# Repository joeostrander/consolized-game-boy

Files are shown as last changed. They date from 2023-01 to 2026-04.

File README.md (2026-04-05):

# consolized-game-boy

This repository contains the current state of the consolized Game Boy project, based on Andy West's original Game Guy project. It's evolved a bit since then, now supporting multiple controller options, custom PCBs, RP2040 and RP2350 support and a newer HDMI-compatible DVI output path with audio (no VGA2HDMI adapter required).

The core idea is still the same: build a self-contained Game Boy console around harvested Game Boy hardware, with video, controls, power, and enclosure work integrated into a compact custom build.

Recent major addition:
- 2026-04-04: HDMI-compatible DVI firmware and hardware path, including digital video plus audio output.

gameplay

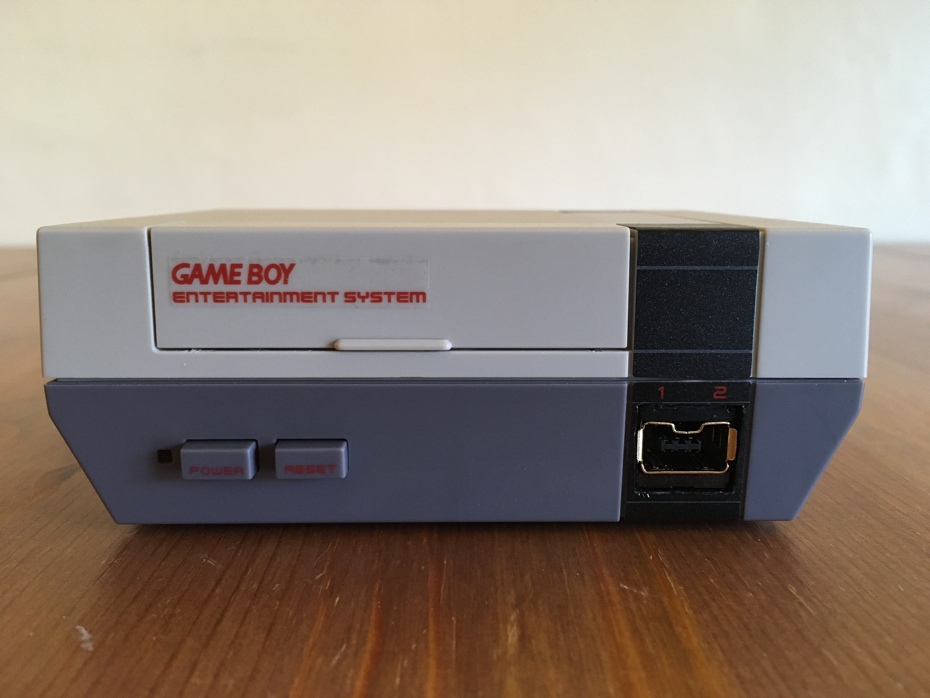
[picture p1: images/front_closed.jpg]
front closed


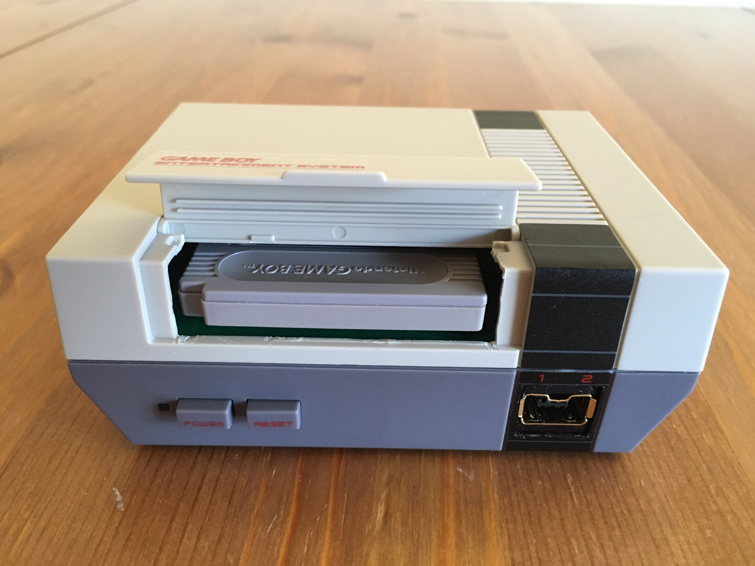
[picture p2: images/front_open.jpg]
front open


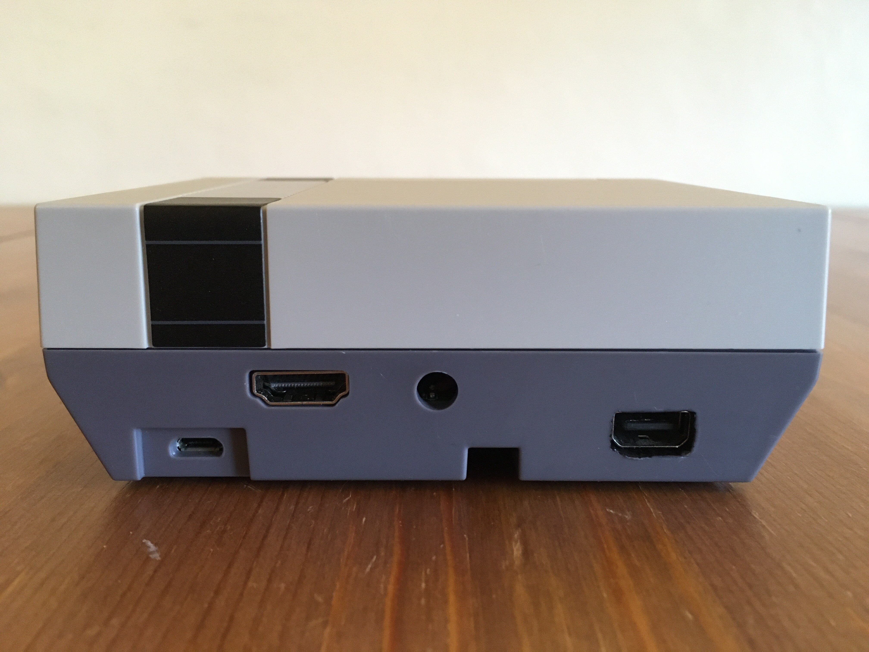
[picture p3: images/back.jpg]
back


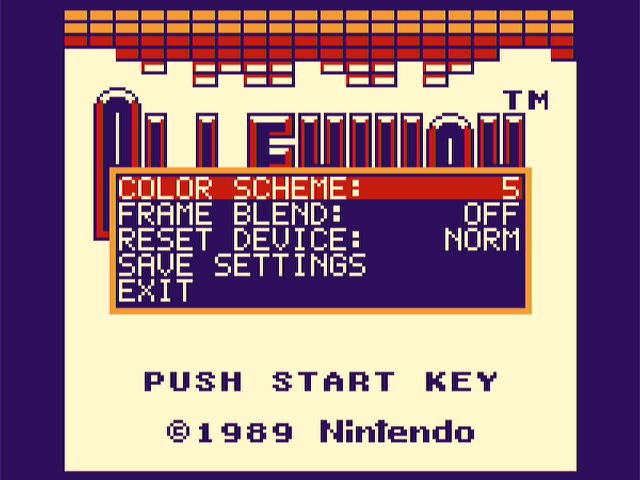
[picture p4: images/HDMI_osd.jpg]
hdmi osd


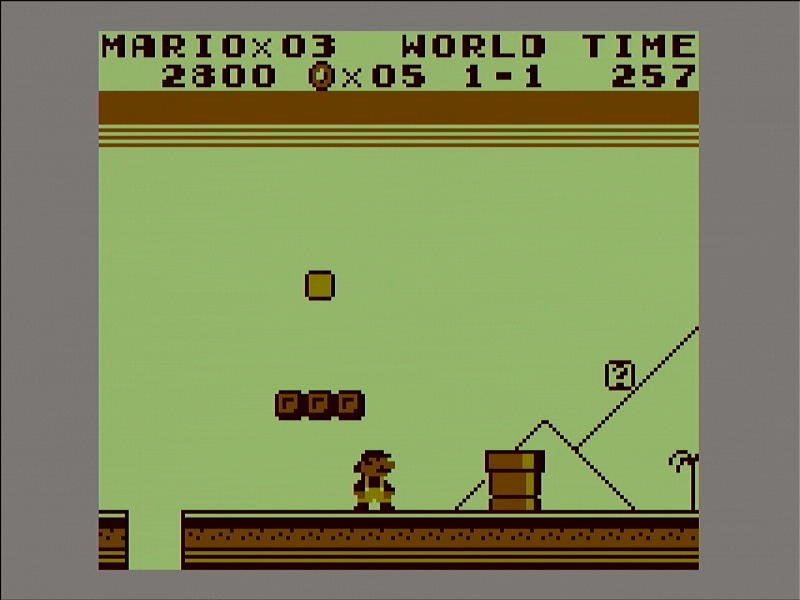
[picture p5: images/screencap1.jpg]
screencap 1


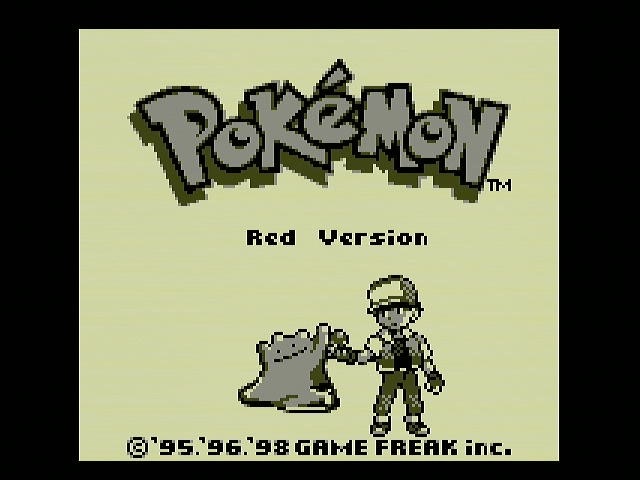
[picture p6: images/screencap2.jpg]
screencap 2


HDMI (DVI)

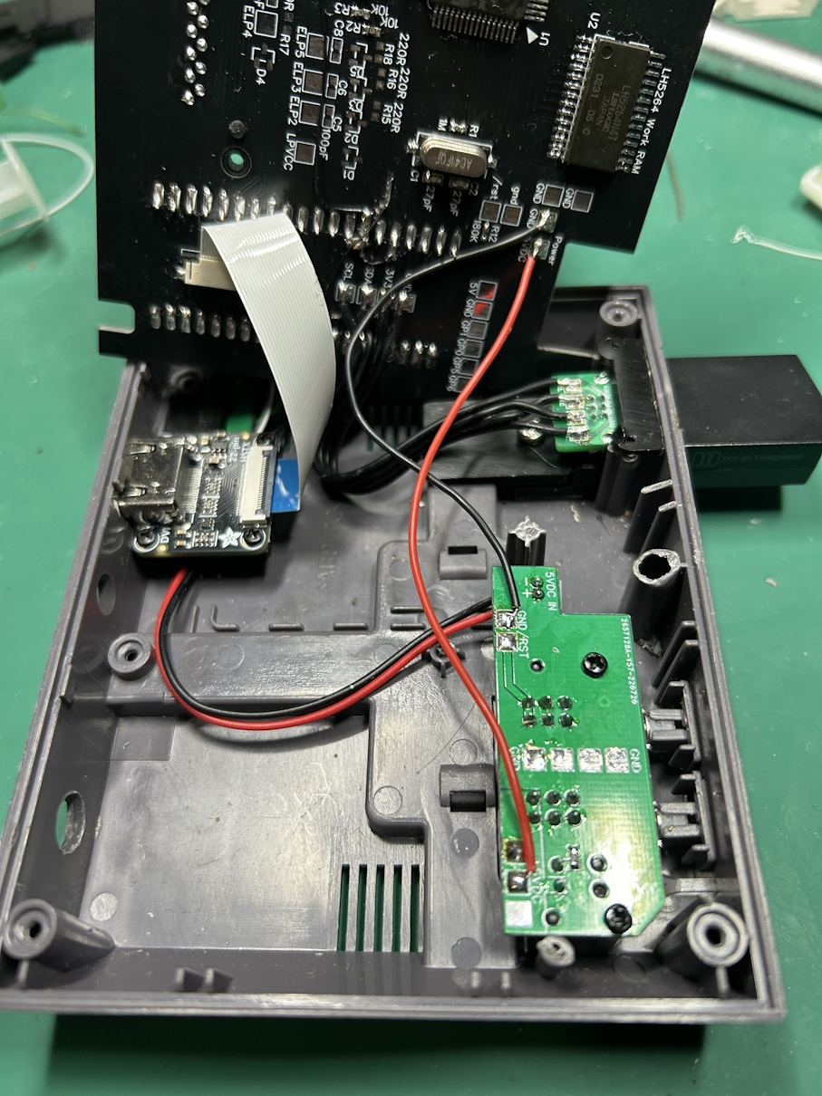
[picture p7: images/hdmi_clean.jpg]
hdmi clean


## What This Project Includes

- Single-Pico firmware designs
- VGA output firmware with RGB222 and RGB332 variants
- HDMI-compatible DVI output firmware with audio
- RP2040 and RP2350 build targets
- NES shift-register controller support
- NES Classic / Wii I2C controller support
- On-screen display for settings and runtime controls
- Saved settings in flash
- Custom motherboard and breakout PCBs
- 3D-printable case and mount parts
- Support for harvesting CPU and RAM from a Super Game Boy SNES/Famicom cartridge
- Link port support, with credit to Markeno for the PCB mod

## Repository Layout

| Path | Purpose |
| --- | --- |
| `src/gb_vga` | VGA firmware project |
| `src/gb_dvi` | HDMI-compatible DVI firmware project |
| `src/buildall.cmd` | Batch wrapper that builds every currently scripted firmware variant |
| `src/find_picotool.cmd` | Shared helper that tries to reuse an existing `picotool` build |
| `src/find_rpi_rp2_drive.cmd` | Shared helper that detects a mounted `RPI-RP2` device |
| `docs` | BOMs and PDF schematics |
| `easyeda` | EasyEDA project archives |
| `gerber` | Gerber archives for motherboard and breakout boards |
| `3D` | STL files for mounts, controller jack holders, and case-specific pieces |
| `images` | Photos, screenshots, and wiring / PCB reference images |

## Hardware Assets

The repository now contains the hardware files needed to reproduce both the VGA and DVI versions.

### Documentation

- `docs/VGA_BOM_V3_2_2_SGB_CART_2023-01-14.csv`
- `docs/VGA_schematic_sgb_cart_V3.2.2_2023-01-18.pdf`
- `docs/HDMI_BOM_SGB_CART.csv`
- `docs/HDMI_schematic_dvi_V2.pdf`

### PCB Archives

EasyEDA source archives are in `easyeda/`.

Gerbers are in `gerber/`, including:

- VGA SGB-cart motherboard variants
- VGA SMD-cart motherboard variant
- HDMI / DVI SGB-cart motherboard variant
- Link port breakout
- NES breakout
- Power / reset board
- USB with data board
- Wii jack breakout

### 3D Printed Parts

STLs are in `3D/`, including VGA and HDMI-specific mounts and Wii jack holder parts.

## Firmware Variants

There are now two firmware families in the repo.

### 1. VGA firmware

Project path:

- `src/gb_vga`

Prebuilt release naming:

- `gb_vga_<platform>_<video>_<controller>.uf2`

Examples:

- `gb_vga_rp2040_rgb222_nes.uf2`
- `gb_vga_rp2040_rgb332_wii.uf2`
- `gb_vga_rp2350_rgb222_nes.uf2`

Options:

- `platform`: `rp2040` or `rp2350`
- `video`: `rgb222` or `rgb332`
- `controller`: `nes` or `wii`

Notes:

- `rgb222` uses fewer GPIOs and is the default VGA output mode in the build script.
- `wii` means the NES Classic / Wii I2C controller path.
- `nes` means the original shift-register controller path.

### 2. HDMI-compatible DVI firmware

Project path:

- `src/gb_dvi`

Prebuilt release naming:

- `dmg_dvi_<platform>_res<mode>_<controller>.uf2`

Examples:

- `dmg_dvi_rp2040_res0_nes.uf2`
- `dmg_dvi_rp2040_res2_wii.uf2`
- `dmg_dvi_rp2350_res1_wii.uf2`

Options:

- `platform`: `rp2040` or `rp2350`
- `mode`: `0`, `1`, or `2`
- `controller`: `nes` or `wii`

Display modes:

- `0`: 640x480 output, horizontally scaled x4 and vertically x3 for full-screen 640x480 presentation
- `1`: 800x600 output, horizontally scaled x4 and vertically x4 for a 640x576 window
- `2`: 640x480 output, horizontally scaled x2 and vertically x2 for a 320x288 window

## Prebuilt Firmware

If you do not want to build from source, use the `.uf2` files from the [Releases](https://github.com/joeostrander/consolized-game-boy/releases) page.

Current release coverage in this repository includes:

- 12 DVI variants: 2 platforms x 3 display modes x 2 controller types
- 8 VGA variants: 2 platforms x 2 video formats x 2 controller types

Choose the file that matches:

1. Your board: `rp2040` for Pico, `rp2350` for Pico 2
2. Your output path: `gb_vga_*` for VGA, `dmg_dvi_*` for HDMI-compatible DVI
3. Your controller wiring: `nes` or `wii`
4. Your display mode: `rgb222` / `rgb332` for VGA, or `res0` / `res1` / `res2` for DVI

To flash, hold BOOTSEL on the Pico / Pico 2, connect USB, then copy the matching `.uf2` to the `RPI-RP2` drive.

## Building From Source

The firmware projects can now be built from this repository directly; they do not need to live under `C:\VSARM\sdk\pico`.

### Common Requirements

- Windows build environment with `cmake` and MinGW available on `PATH`
- A valid Pico SDK checkout exposed via `PICO_SDK_PATH`
- `picotool` available if you want `.uf2` output

The wrapper scripts try to reuse an existing `picotool` package from a sibling VSARM `gb_vga` or `gb_dvi` build when one is available.

If a target device is mounted as `RPI-RP2`, the build scripts will also try to copy the generated `.uf2` automatically.

### Building VGA

Extra requirement for VGA:

- Pico Extras must be available through `PICO_EXTRAS_PATH`, or placed as a sibling of the SDK checkout so `pico_scanvideo_dpi` can be found.

Build from `src/gb_vga`:

```bat
build_clean.cmd
build_clean.cmd rp2040 rgb222 nes
build_clean.cmd rp2040 rgb332 wii
build_clean.cmd rp2350 rgb222 nes
build_clean.cmd rp2350 rgb332 wii
```

Argument format:

```text
build_clean.cmd [rp2040|rp2350] [rgb222|rgb332] [nes|wii]
```

### Building DVI

Build from `src/gb_dvi`:

```bat
build_clean.cmd
build_clean.cmd rp2040 0 nes
build_clean.cmd rp2350 2 wii

build.cmd
build.cmd rp2040 0 nes
build.cmd rp2350 2 wii
```

Argument format:

```text
build_clean.cmd [rp2040|rp2350] [0|1|2] [nes|wii]
build.cmd       [rp2040|rp2350] [0|1|2] [nes|wii]
```

Notes:

- `build_clean.cmd` always recreates the build directory.
- `build.cmd` tries to reuse the existing build and will recreate it if cached settings no longer match the requested platform, resolution mode, or controller type.

### Building Every Scripted Variant

From `src/`:

```bat
buildall.cmd
```

This runs the full scripted matrix for both projects:

- 12 DVI builds
- 8 VGA builds

It stops on the first failure so the failing variant is easy to identify.

## Project Notes

- VGA uses Pico Extras because `pico_scanvideo_dpi` is provided there.
- DVI does not need Pico Extras.
- The DVI firmware supports audio output in addition to digital video.
- Both firmware families expose controller selection at build time.
- Both firmware families now support RP2040 and RP2350 targets.

## Videos

Demo:

RGB332 Video Demo (https://youtu.be/dT88XEHc5w8)

Andy liked my modifications and made an updated video where he built one with my changes:

The Game Guy Mini, Upgrading the Unportable Game Boy! (https://youtu.be/gPNHySf-hk0)

Original video:

Game Guy - The Unportable Game Boy (https://www.youtube.com/watch?v=ypGMU5lLjeU)

element14 Community pages:

- https://community.element14.com/challenges-projects/element14-presents/project-videos/w/documents/27407
- https://community.element14.com/w/documents/27862/episode-577-the-game-guy-mini-upgrading-the-unportable-game-boy

## Credits

- Andy West for the original concept and code
- Joe Ostrander for the later firmware, hardware, controller, OSD, flash-save, scaling, and newer DVI work in this repo
- Markeno for the link port PCB motherboard design addition
- Supertazon for waterslide logo and help on frameblending
- other members of element14 community that I've forgot

## See also

- [PicoDVI-DMG](https://github.com/joeostrander/PicoDVI-DMG)
- [PicoDVI-DMG_EMU](https://github.com/joeostrander/PicoDVI-DMG_EMU) - Emulator version

## Contact
For questions or collaboration, reach me at:  
joeostrander [at] protonmail [dot] com

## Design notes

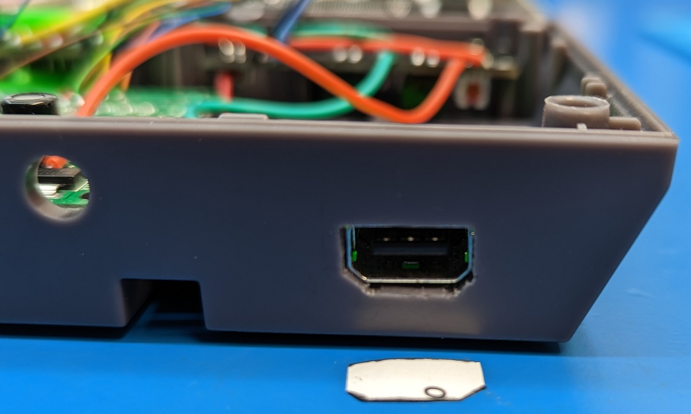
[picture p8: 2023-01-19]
images/v3_2_lp5.jpg

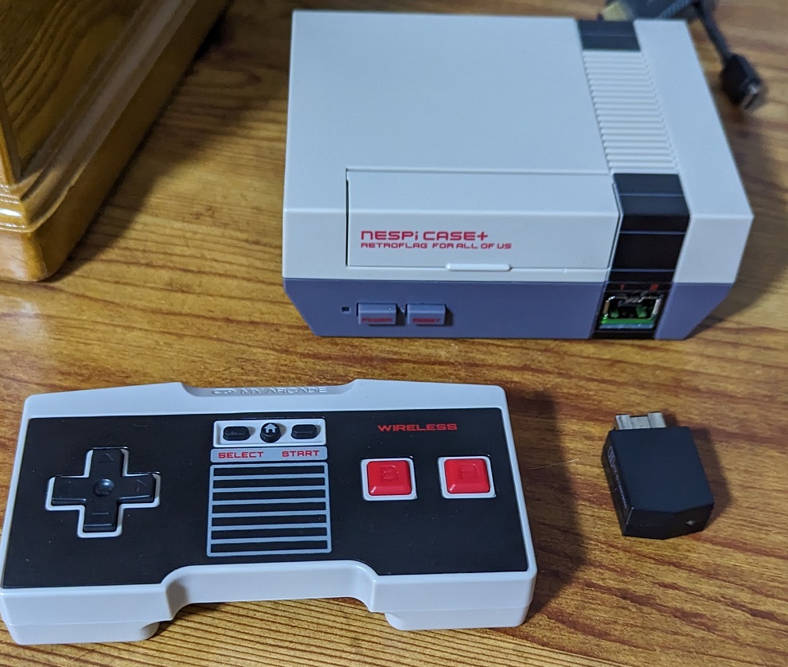
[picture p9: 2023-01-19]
images/v3_2_front.jpg

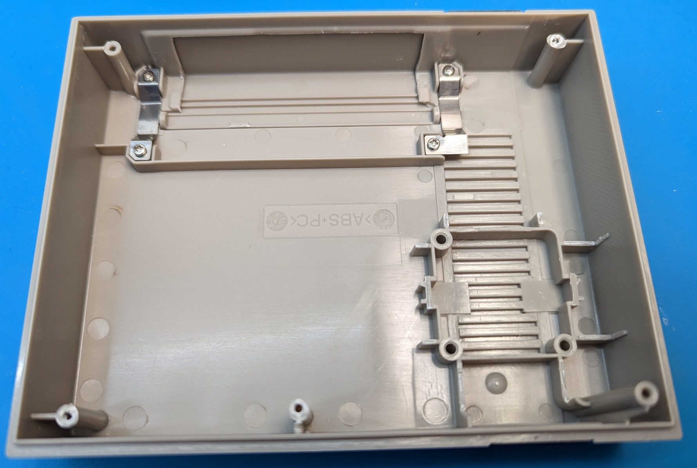
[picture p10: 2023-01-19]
images/v3_2_top_inside.jpg

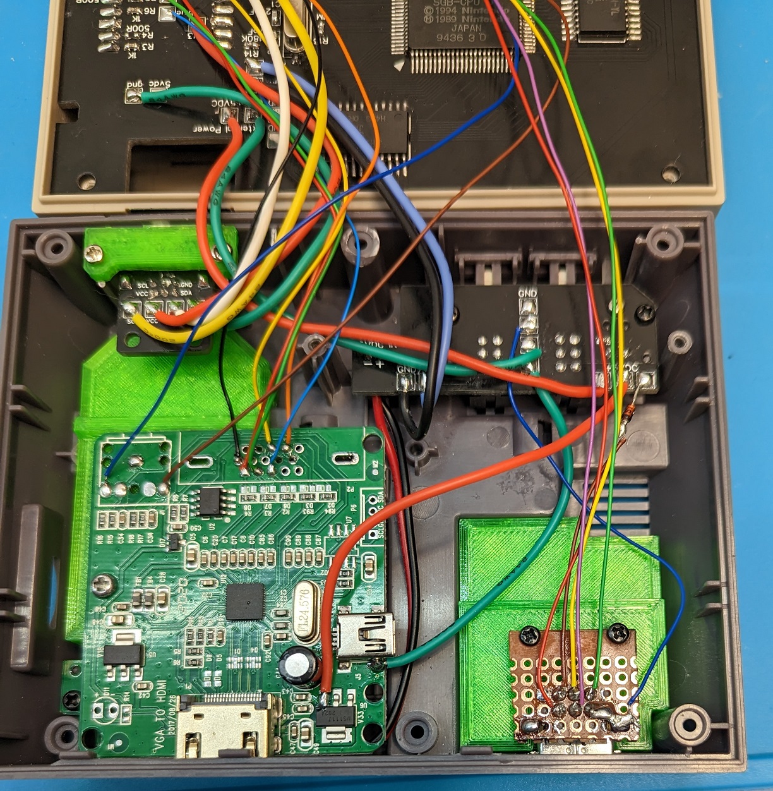
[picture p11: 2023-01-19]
images/v3_2_lp7.jpg

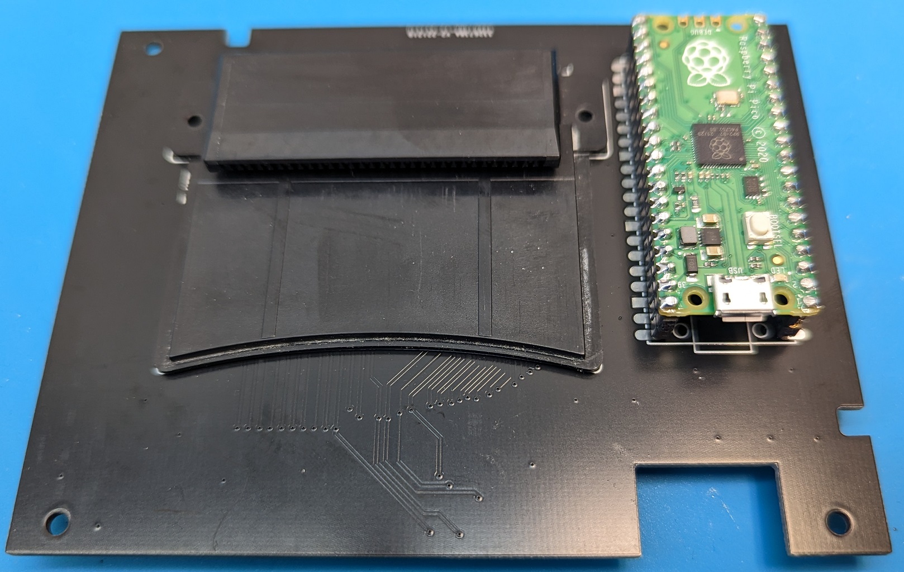
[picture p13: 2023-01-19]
images/v3_2_topside.jpg

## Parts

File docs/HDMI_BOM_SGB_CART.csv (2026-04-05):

Game Boy Console BOM
Name | Designator | Footprint | Quantity | Manufacturer Part | Manufacturer | Link
0524352272 "U7" "524352272" "1" "0524352272" "MOLEX" "https://www.digikey.com/en/products/detail/molex/0524352272/775697"
27pF | C1,C2 | 0603 CAPACITOR | 2 | C1608C0G1H270J080AA | TDK Corporation | https://www.digikey.com/en/products/detail/tdk-corporation/C1608C0G1H270J080AA/513761
1uF Tantalum Polarized Capacitor | C3,C4 | 1411 CAP-SMD_L3.5-W2.8-R-RD | 2 | T491B105K050AT | KEMET | https://www.digikey.com/en/products/detail/kemet/T491B105K050AT/3724722
100pF | C5,C6,C7,C8 | 0603 CAPACITOR | 4 | 06035A101JAT2A | KYOCERA AVX | https://www.digikey.com/en/products/detail/kyocera-avx/06035A101JAT2A/563285
4.7nF "C9" "0603 CAPACITOR" "1" "CAPCERAMIC0.22UF16V20%X5R0201" "null" ""
10uF "C10" "0603 CAPACITOR" "1" "CAPCERAMIC0.22UF16V20%X5R0201" "null" ""
MMBD7000HS-7-F | D1,D2,D3,D4,D5 | SOT-23-3_L2.9-W1.3-P1.90-LS2.4-BR | 5 | MMBD7000HS-7-F | Diodes Incorporated | https://www.digikey.com/en/products/detail/diodes-incorporated/MMBD7000HS-7-F/2179586
1M | R1 | RESISTOR_R0603 | 1 | WR06X105 JTL | Walsin Technology Corporation | https://www.digikey.com/en/products/detail/walsin-technology-corporation/WR06X105-JTL/13239221
10K | R2,R3 | RESISTOR_R0603 | 2 | RNCP0603FTD10K0 | Stackpole Electronics Inc | https://www.digikey.com/en/products/detail/stackpole-electronics-inc/RNCP0603FTD10K0/2240139
180K | R12 | RESISTOR_R0603 | 1 | RC0603JR-07180KL | YAGEO | https://www.digikey.com/en/products/detail/yageo/RC0603JR-07180KL/726723
220R | R15,R16,R17,R18,R19(Power/Reset Board) | RESISTOR_R0603 | 5 | RMCF0603FT220R | Stackpole Electronics Inc | https://www.digikey.com/en/products/detail/stackpole-electronics-inc/RMCF0603FT220R/1760809
0R "R4" "RESISTOR_R0603" "1" "" "" ""
33K "R5 | R6" "RESISTOR_R0603" "2" "" "" ""
1.5K "R7 | R8" "RESISTOR_R0603" "2" "" "" ""
ABLS-4.194304MHZ-D-4-Y-T | X2 | CRYSTAL-SMD_L11.4-W4.7-LS12.7 | 1 | ABLS-4.194304MHZ-D-4-Y-T | ABRACON | https://www.digikey.com/en/products/detail/abracon-llc/ABLS-4-194304MHZ-D-4-Y-T/9997833
SN74LVC245ANSR | U4 | SOIC-20_L13.3-W5.5-P1.27-LS7.8-BL | 1 | SN74LVC245ANSR | TI | https://www.digikey.com/en/products/detail/texas-instruments/SN74LVC245ANSR/499514
Raspberry Pi Pico | U5 | RASPBERRY-PI-PICO | 1 | SC0915 | Raspberry Pi | https://www.digikey.com/en/products/detail/raspberry-pi/SC0915/13624793
Super Gameboy Cartridge Header | U6 | SUPER GAMEBOY CARTRIDGE HEADER | 1 |  | Nintendo | From Super Game Boy
DMG-CPU | U1 | DMG-CPU-B | 1 |  | Nintendo | From Super Game Boy
LH5264 RAM | U2,U3 | DMG LH5264 | 2 |  | Nintendo | From Super Game Boy
Retroflag NESPi Case Plus |  |  | 1 |  |  | https://a.co/d/1K0sy7a
Super Gameboy Cartridge (to source the CPU, RAM and Cartridge Port) |  |  | 1 |  | Nintendo | Search Ebay
Wii/NES Classic Port 90 degree (Optional this or the Original NES Port) |  |  | 1 |  |  | https://www.aliexpress.us/item/3256804436132647.html
Original NES Controller Port (Optional this or the Wii Port) |  |  | 1
Pin strip / header (for the Pico if it didn’t come with them) |  |  | 1
Wire 24awg Silicone Insulated Wire |  |  |  |  |  | https://www.amazon.com/gp/product/B07TJXRGXM/?th=1
Wire 30awg Insulated Wire |  |  |  |  |  | https://www.amazon.com/Treedix-Copper-Wrapping-Jumper-Optional/dp/B08D6D1TKH/
Super Game Boy Console Main Board PCB | sgb_cart_motherboard (hdmi/dvi variant)
Power and Reset Board PCB | power_reset_v3_21
Wii Controller Breakout Board PCB (Optional this or the NES Breakout) | wii_jack_w_holes_v3_21
NES Controller Breakout Board PCB (Optional) | nes_breakout_v3
DMG Game Link Multiplayer Breakout PCB (Optional) | dmg_link_v3_21
USB Power with Data PCB (Optional, to Program the Pico in the case) | pcb_v3_usb_w_data
Adafruit RP2350 22-pin FPC HSTX to DVI Adapter for HDMI Displays |  |  | 1 | 6055 | Adafruit | https://www.adafruit.com/product/6055
22-pin 0.5mm pitch FPC Flex Cable for DSI CSI or HSTX - 10cm |  |  | 1 | 6035 | Adafruit | https://www.adafruit.com/product/6035
22-pin 0.5mm pitch FPC Flex Cable for DSI CSI or HSTX - 5cm |  |  | 1 | 6034 | Adafruit | https://www.adafruit.com/product/6034

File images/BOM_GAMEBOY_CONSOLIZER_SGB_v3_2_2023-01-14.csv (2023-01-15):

 | Super Game Boy Console Main Board
ID | Name | Designator | Footprint | Quantity | Manufacturer Part | Manufacturer
1 | 27pF | C2,C1 | 0603 CAPACITOR | 2 | C1608C0G1H270J080AA | TDK Corporation
2 | 1uF | C4,C3 | CAP-SMD_L3.5-W2.8-R-RD | 2 | T491B105K050AT | KEMET
3 | 100pF | C5,C6,C7,C8 | 0603 CAPACITOR | 4 | 06035A101JAT2A | KYOCERA AVX
4 | MMBD7000HS-7-F | D1,D2,D3,D4,D5 | SOT-23-3_L2.9-W1.3-P1.90-LS2.4-BR | 5 | MMBD7000HS-7-F | Diodes Incorporated
5 | 1M | R1 | RESISTOR_R0603 | 1 | WR06X105 JTL | Walsin Technology Corporation
6 | 47R | R10,R11 | RESISTOR_R0603 | 2 | RC0603JR-0747RL | YAGEO
7 | 180K | R12 | RESISTOR_R0603 | 1 | RC0603JR-07180KL | YAGEO
8 | 510R | R13,R14 | RESISTOR_R0603 | 2 | RC0603JR-07510RL | YAGEO
9 | 220R | R15,R16,R17,R18 | RESISTOR_R0603 | 4 | RMCF0603FT220R | Stackpole Electronics Inc
10 | 10K | R2,R3 | RESISTOR_R0603 | 2 | RNCP0603FTD10K0 | Stackpole Electronics Inc
11 | 1K | R4,R8,R6 | RESISTOR_R0603 | 3 | RMCF0603FG1K00 | Stackpole Electronics Inc
12 | 500R | R5,R7,R9 | RESISTOR_R0603 | 3 | RT0603BRC07500RL | YAGEO
13 | DMG-CPU-B | U1 | DMG-CPU-B | 1
14 | LH5264 Work RAM | U2 | DMG LH5264 | 1
15 | LH5264 Video RAM | U3 | DMG LH5264 | 1
16 | SN74LVC245ANSR | U4 | SOIC-20_L13.3-W5.5-P1.27-LS7.8-BL | 1 | SN74LVC245ANSR | TI
17 | Raspberry Pi Pico | U5 | RASPBERRY-PI-PICO | 1 | SC0915 | Raspberry Pi
18 | Super Gameboy Cartridge Header | U6 | SUPER GAMEBOY CARTRIDGE HEADER | 1
19 | ABLS-4.194304MHZ-D-4-Y-T | X2 | CRYSTAL-SMD_L11.4-W4.7-LS12.7 | 1 | ABLS-4.194304MHZ-D-4-Y-T | ABRACON
 | Super Game Boy Console Power/Reset Board
1 | 510R | R19 | RESISTOR_R0603 | 1 | RC0603JR-07510RL | YAGEO
 | GANA VGA to HDMI, 1080P Full HD Mini VGA to HDMI Audio Video Converter | https://www.amazon.com/GANA-Converter-Adapter-Computer-Projector/dp/B01N53IESF
 | Retroflag NESPi Case Plus | https://www.amazon.com/dp/B07BRHDVTN?psc=1&ref=ppx_yo2ov_dt_b_product_details

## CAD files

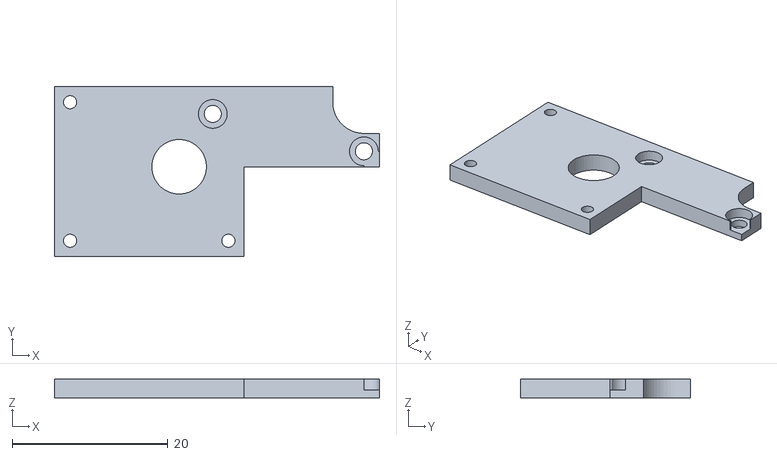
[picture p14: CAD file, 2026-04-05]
3D/HDMI_hstx_mount.stl
41.7 x 21.8 x 2.40

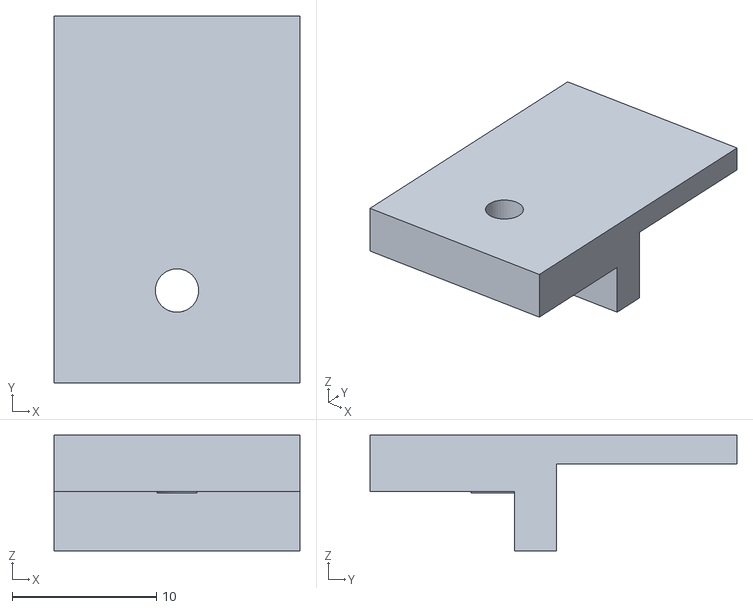
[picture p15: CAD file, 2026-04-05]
3D/HDMI_wii_jack_holder_bottom_retainer_v2.stl
17.0 x 25.4 x 8.00

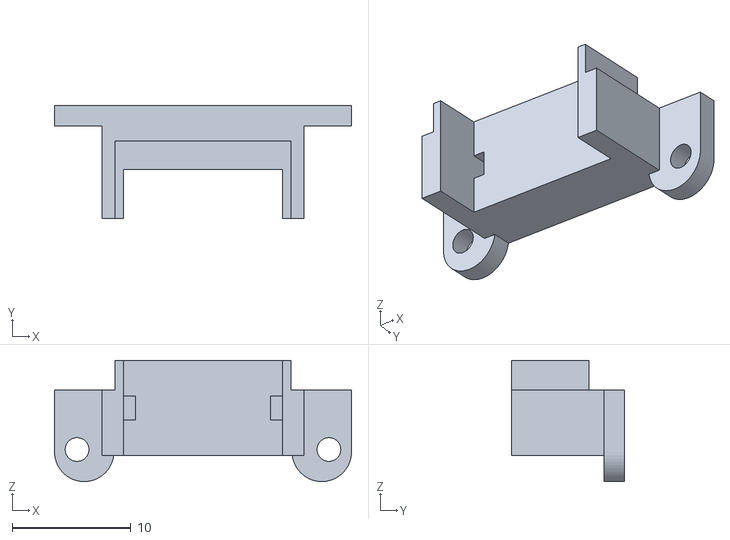
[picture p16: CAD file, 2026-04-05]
3D/HDMI_wii_jack_holder_top_v2.stl
25.0 x 9.50 x 10.2

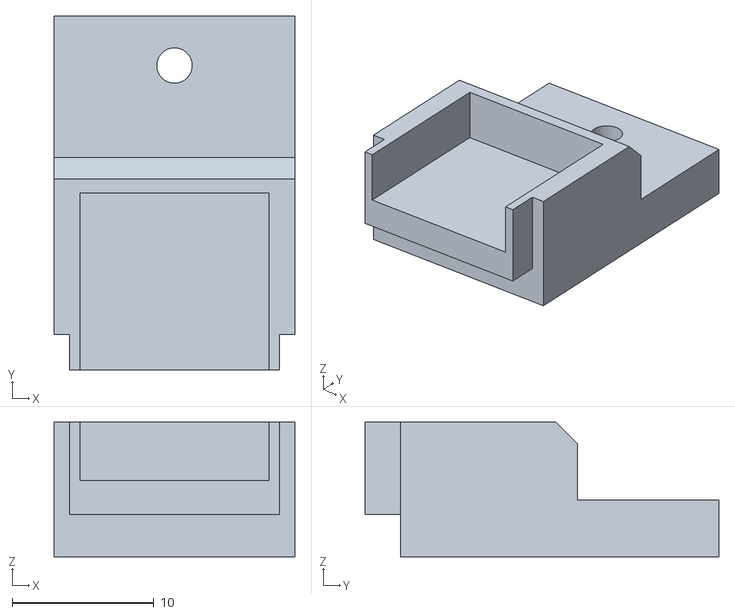
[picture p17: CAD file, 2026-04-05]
3D/HDMI_wii_jack_holder_bottom_v2.stl
17.0 x 25.0 x 9.50

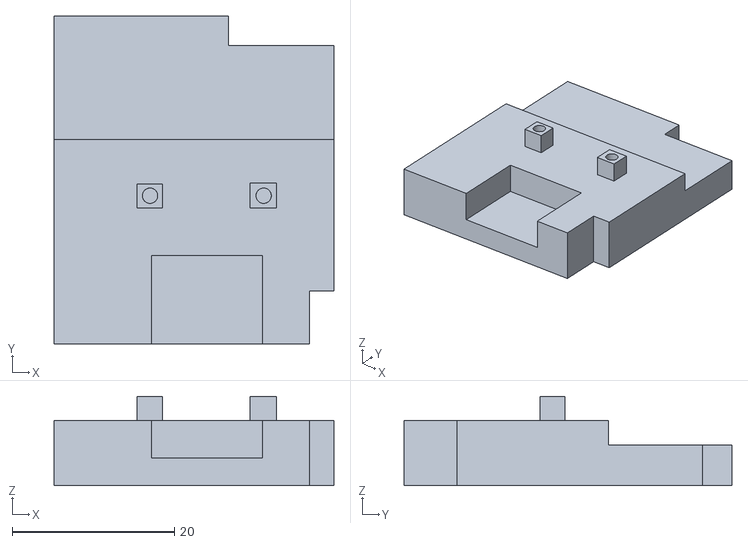
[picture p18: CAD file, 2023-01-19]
3D/dmg_link_mount.stl
34.5 x 40.4 x 11.0

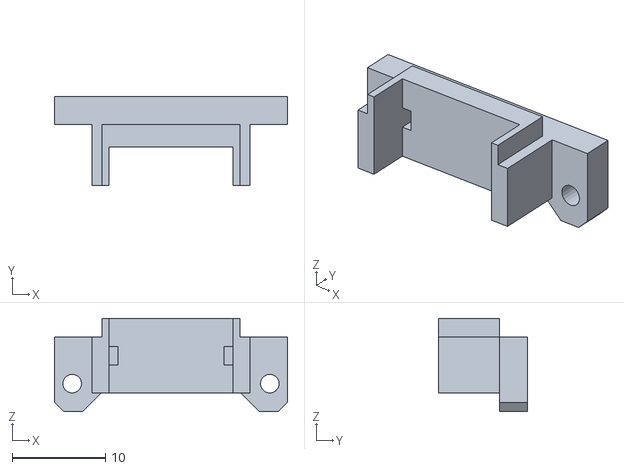
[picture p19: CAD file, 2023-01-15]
3D/wii_jack_holder_top.stl
25.0 x 9.50 x 10.0

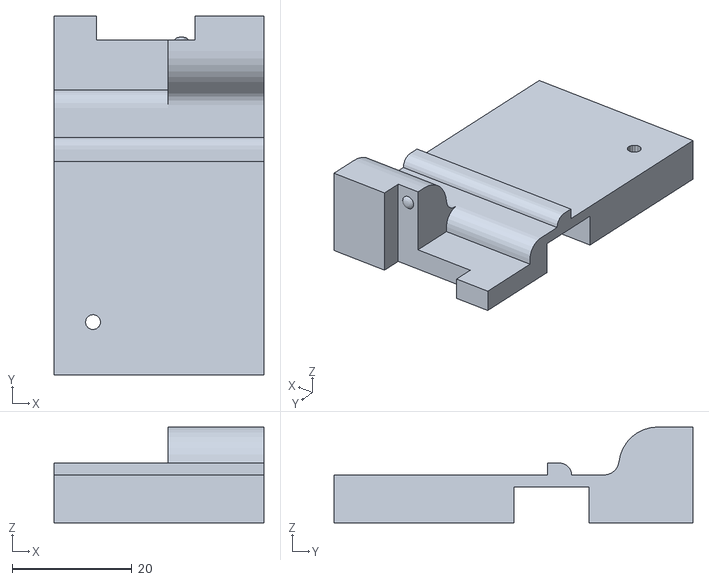
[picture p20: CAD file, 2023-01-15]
3D/VGA_nes_and_vga2hdmi.stl
35.0 x 59.8 x 16.0

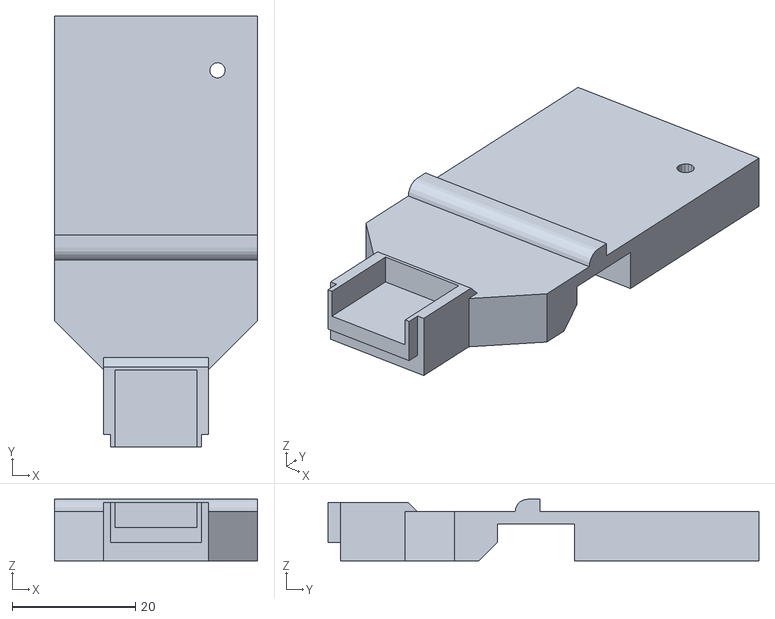
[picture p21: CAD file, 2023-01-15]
3D/VGA_wii_and_vga2hdmi.stl
33.0 x 70.0 x 10.0

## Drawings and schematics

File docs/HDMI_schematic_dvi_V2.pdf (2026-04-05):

## Audio Game Link Parts

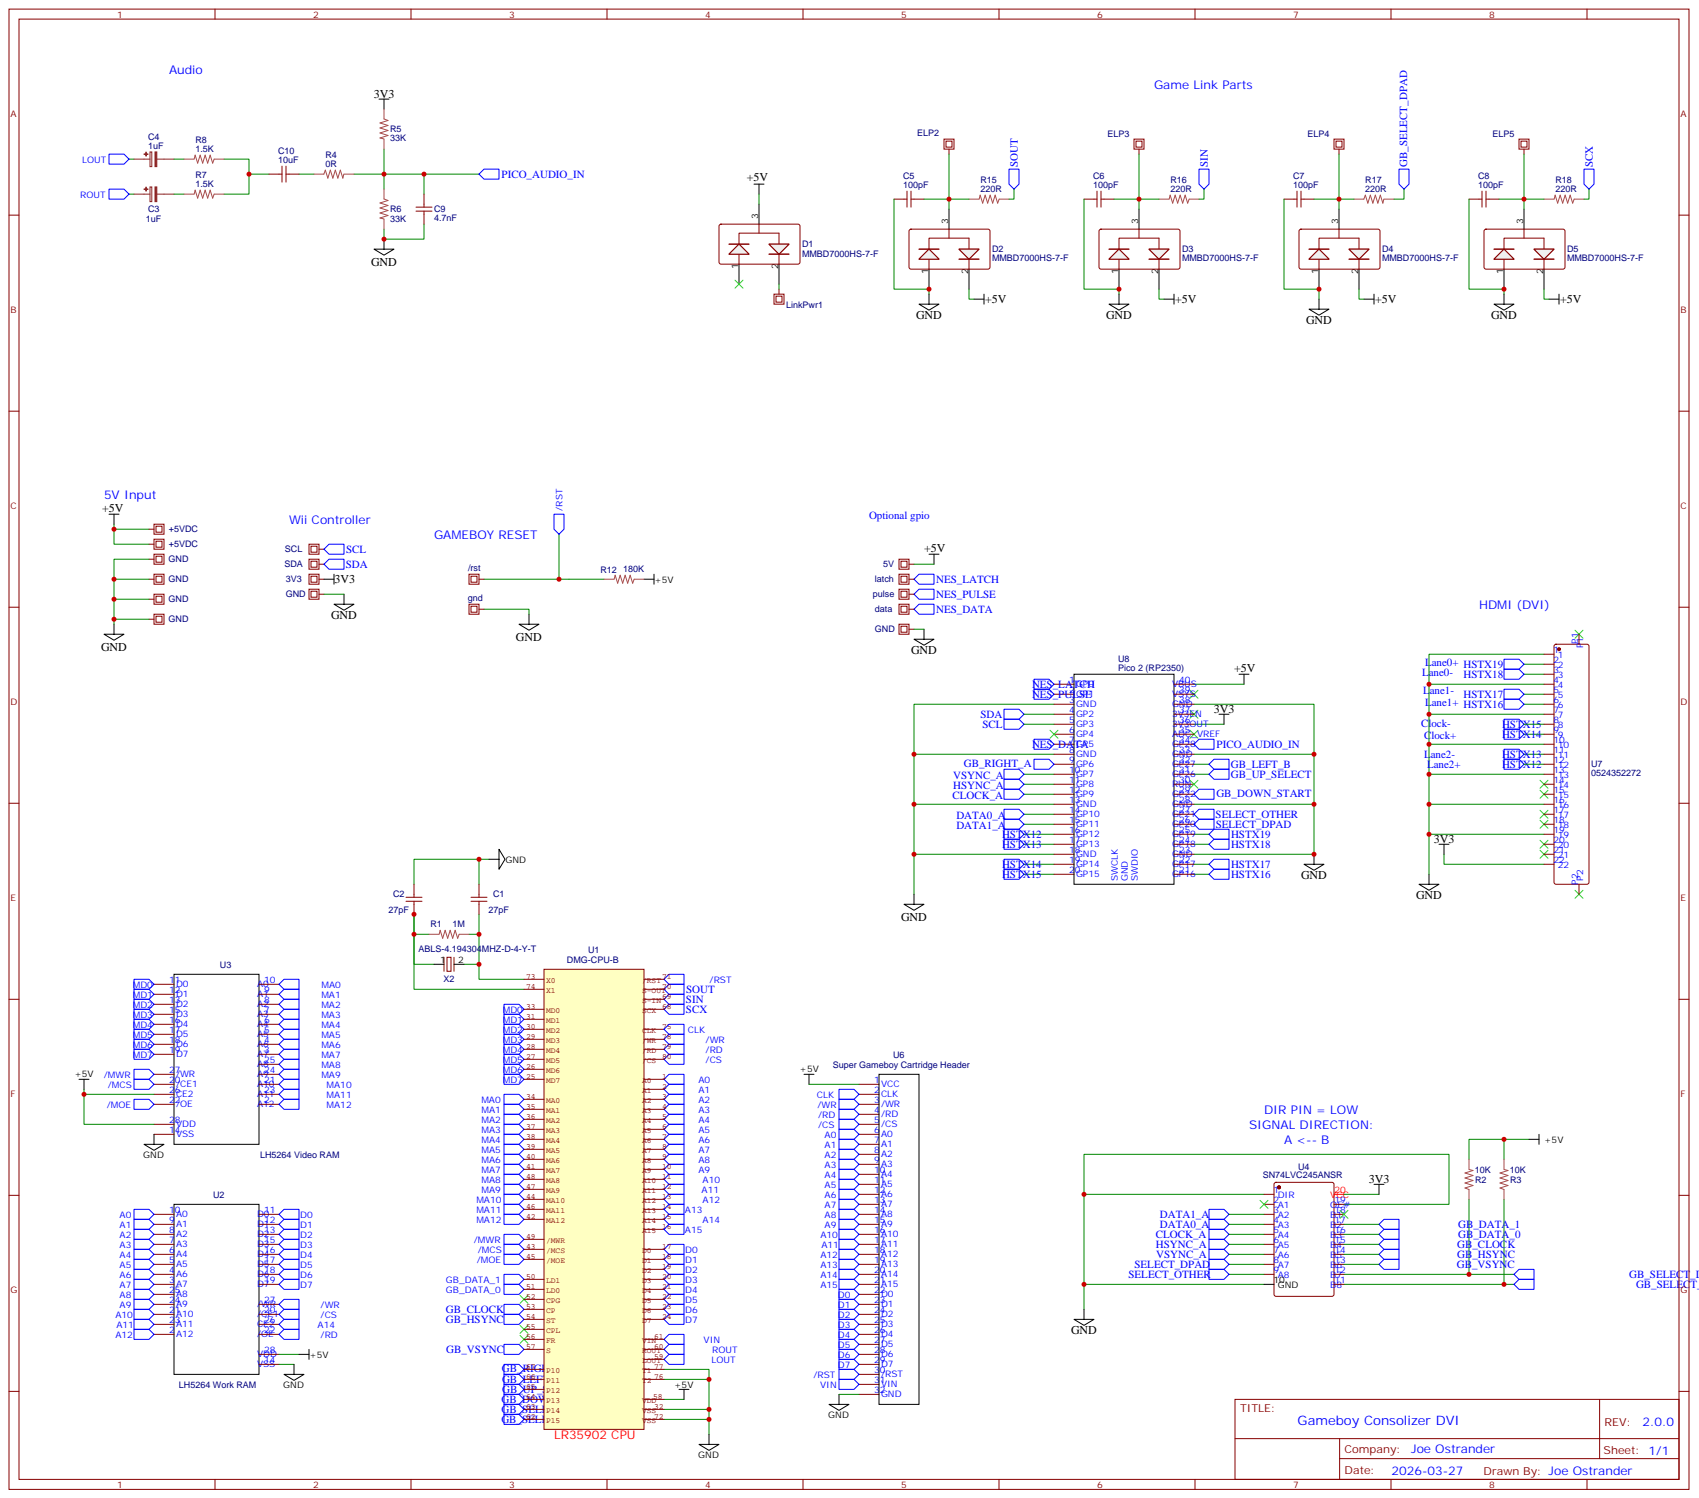
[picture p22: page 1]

Super Gameboy Cartridge Header

Drawn By: Joe Ostrander

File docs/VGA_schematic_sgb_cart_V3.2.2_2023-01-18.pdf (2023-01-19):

## Wii Controller

## To VGA

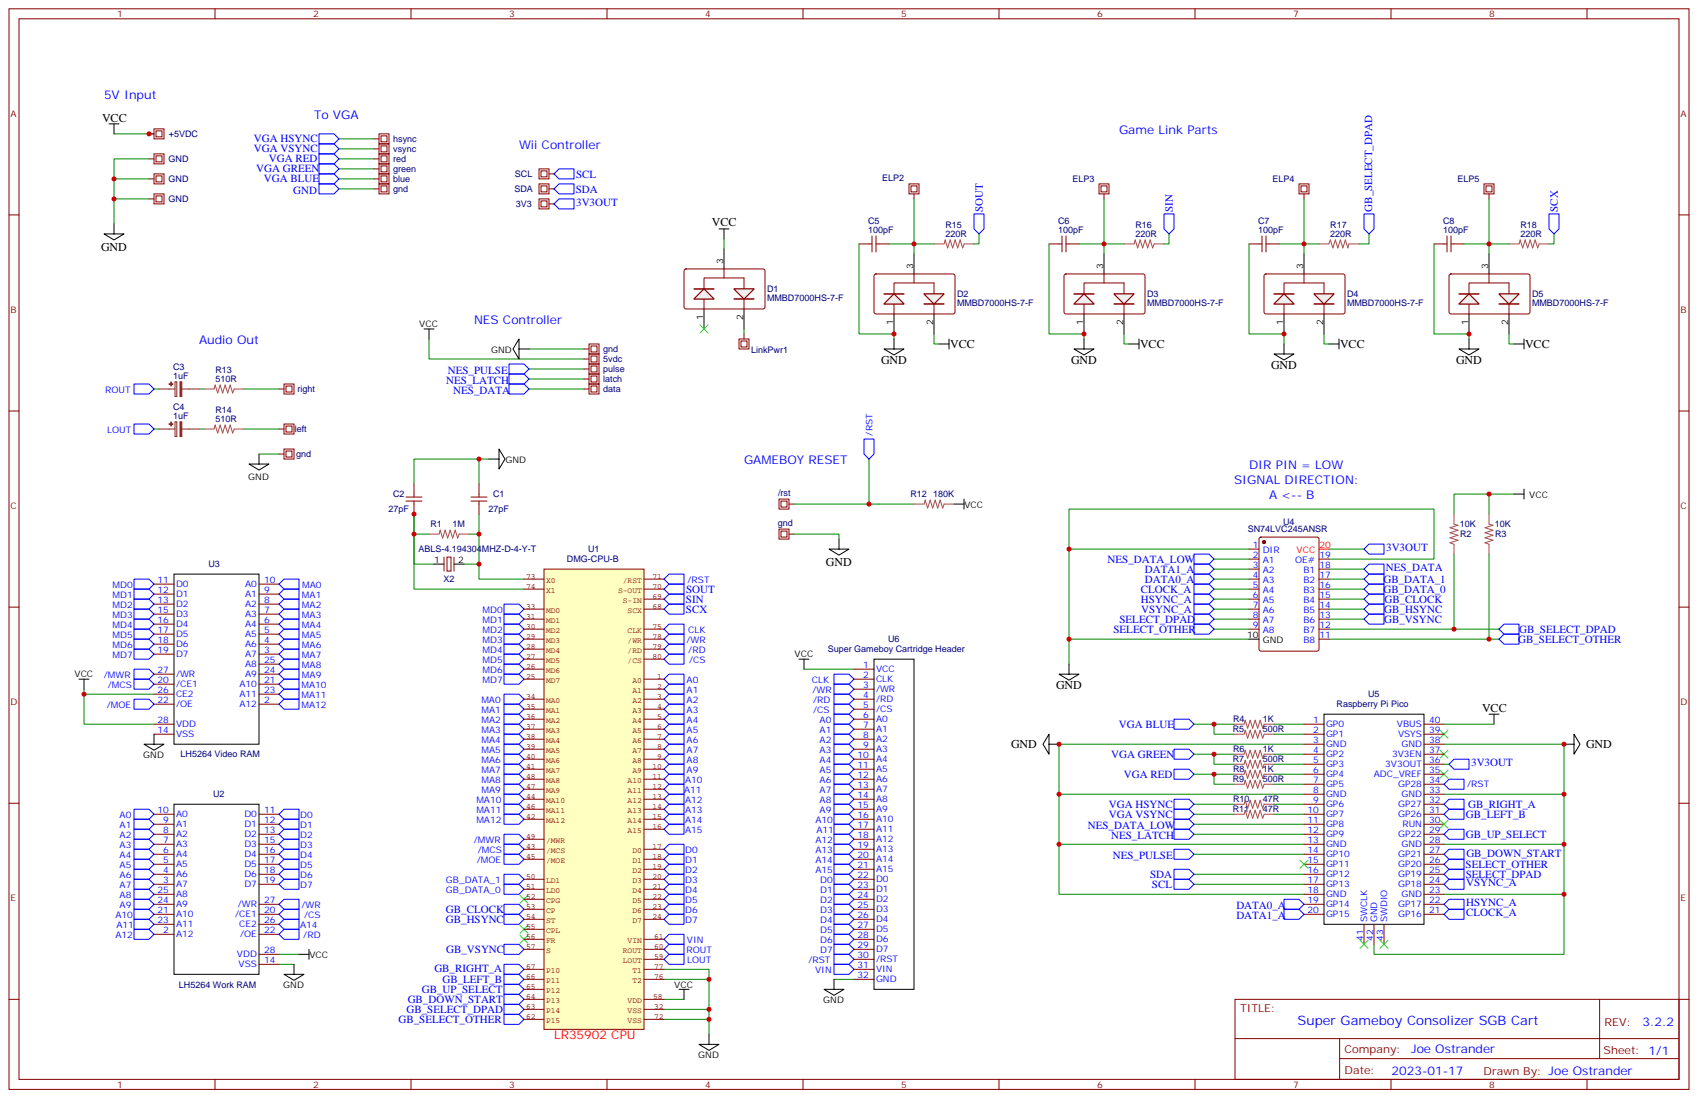
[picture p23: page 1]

Super Gameboy Cartridge Header

Drawn By: Joe Ostrander

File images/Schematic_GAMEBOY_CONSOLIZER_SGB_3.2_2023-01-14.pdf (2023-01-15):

## Game Link Parts

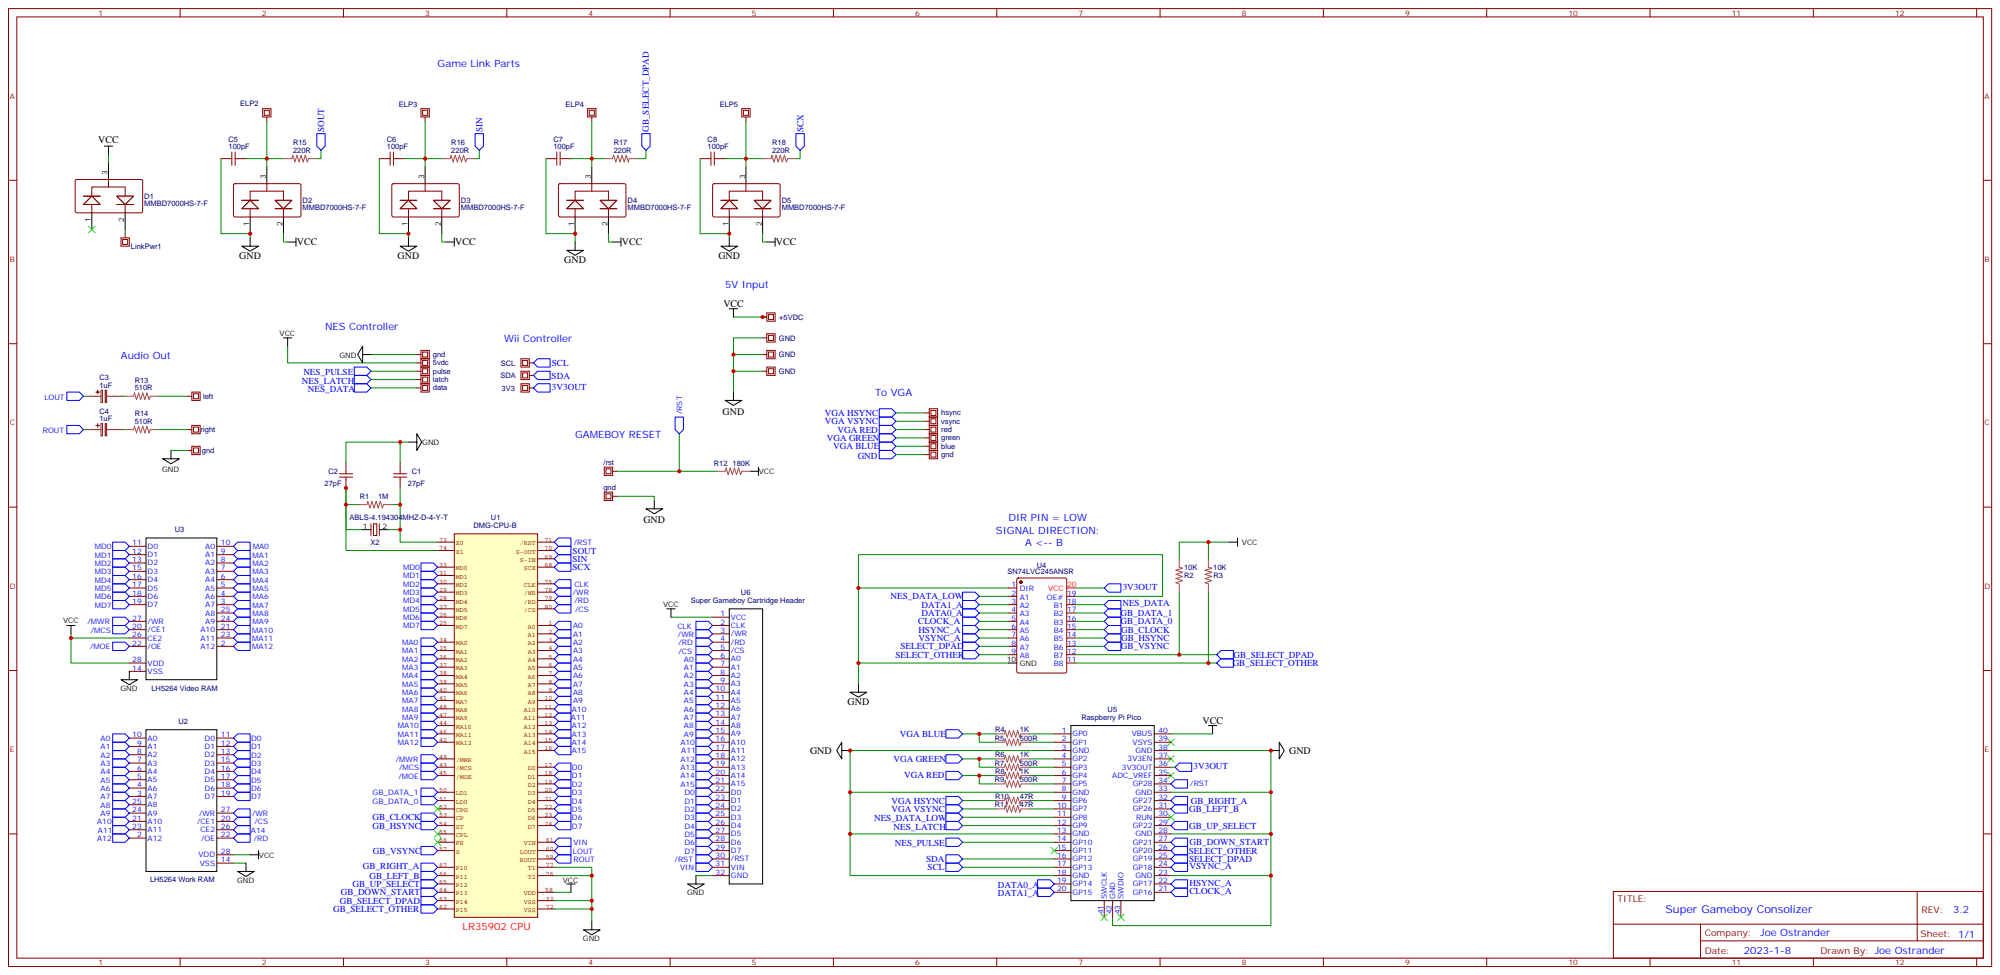
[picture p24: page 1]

Super Gameboy Cartridge Header

Drawn By: Joe Ostrander

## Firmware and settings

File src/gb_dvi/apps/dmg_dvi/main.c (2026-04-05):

/*
TODO:
- Add support for NES shift-register based controller

*/

// Joe Ostrander
// 2026.03.28
// gb_dvi

#pragma GCC optimize("O3")

#include <stdio.h>
#include <stdlib.h>
#include <stdarg.h>
#include <string.h>
#include <hardware/watchdog.h>
#include "hardware/vreg.h"
#include "hardware/i2c.h"
#include "hardware/irq.h"
#include "hardware/sync.h"
#include "hardware/clocks.h"
#include "hardware/regs/intctrl.h"
#include "pico/multicore.h"
#include "pico/stdlib.h"
#include "pico/stdio.h"
#include "pico/stdio_uart.h"
#include "hardware/uart.h"
#include "hardware/adc.h"
#include "hardware/pwm.h"

#include "eeprom.h" // emulated with flash :)
#include "hardware/flash.h"
#include "pico/bootrom.h"

#include "dvi.h"
#include "dvi_serialiser.h"
#include "common_dvi_pin_configs.h"
#include "tmds_encode.h"
#include "audio_ring.h"  // For get_write_size and get_read_size


#include "analog_microphone.h"
#include "emusound.h"
#include "colors.h"
#include "mario.h"
#include "video_defs.h"
#include "osd.h"

#include "video_capture.pio.h"  // PIO-based video capture
#include "shared_dma_handler.h"

// Set to 1 to enable NES Classic / Wii I2C-based controller support
// Set to 0 to use old-school shift register controller support
#ifndef USE_NES_CLASSIC_OR_WII
#define USE_NES_CLASSIC_OR_WII      1
#endif

#define HOME_RESETS_TO_BOOTLOADER   0  // Set to 1 to enable HOME button to reset into USB mass storage mode for easier programming

#define ENABLE_AUDIO                1  // Set to 1 to enable audio, 0 to disable all audio code
#define ENABLE_VIDEO_CAPTURE        1
#define ENABLE_OSD                  1  // Set to 1 to enable OSD code, 0 to disable
#define AUDIO_ON_CORE1              0  // Set to 1 to run audio processing on Core 1 (alongside DVI) to reduce contention with VSYNC GPIO handling on Core 0; set to 0 to run audio on Core 0 with timer IRQ (default)

#define BIT_IS_CLEAR(value, bit)    (((value) & (1U << (bit))) == 0)

#if ENABLE_AUDIO
static const int hdmi_n[6] = {4096, 6272, 6144, 3136, 4096, 6144};  // 32k, 44.1k, 48k, 22.05k, 16k, 24k
static uint16_t rate = SAMPLE_FREQ;
// #define AUDIO_BUFFER_SIZE   (0x1<<8) // Must be power of 2
audio_sample_t audio_buffer[AUDIO_BUFFER_SIZE];

#define AUDIO_GAIN                  1.0f
#define AUDIO_HPF_HZ                0.0f
#define AUDIO_LPF_HZ                0.0f

#define PIN_AUDIO_IN                28 // ADC2
#endif

// #define DEBUG_BUTTON_PRESS

#define ONBOARD_LED_PIN             25

#define DVI_SERIAL_CONFIG           adafruit_hstx_cfg

// GAMEBOY VIDEO INPUT (From level shifter)
#define HSYNC_PIN                   8
#define DATA_1_PIN                 11
#define DATA_0_PIN                 10
#define PIXEL_CLOCK_PIN             9
#define VSYNC_PIN                   7
#define DMG_READING_BUTTONS_PIN    21       // P15 (input, DMG will set HIGH when reading buttons)
#define DMG_READING_DPAD_PIN       20       // P14 (input, DMG will set HIGH when reading D-PAD)
#define DMG_OUTPUT_RIGHT_A_PIN      6       // P10 (output, button 'A' or 'RIGHT' state, depending on DMG_READING pins)
#define DMG_OUTPUT_UP_SELECT_PIN   26       // P12 (output, button 'SELECT' or 'UP' state, depending on DMG_READING pins)
#define DMG_OUTPUT_DOWN_START_PIN  22       // P13 (output, button 'START' or 'DOWN' state, depending on DMG_READING pins)
#define DMG_OUTPUT_LEFT_B_PIN      27       // P11 (output, button 'B' or 'LEFT' state, depending on DMG_READING pins)

#if USE_NES_CLASSIC_OR_WII
// I2C Pins, etc. -- for I2C controller
#define NES_CONTROLLER_INIT_DELAY_MS    1000u
#define NES_CONTROLLER_REINIT_DELAY_MS  1000u
#define SDA_PIN                         2
#define SCL_PIN                         3
#define I2C_ADDRESS                     0x52
i2c_inst_t* i2cHandle = i2c1;
#else
// NES Controller Pins -- for shift register controller
#define PIN_NES_LATCH                   0
#define PIN_NES_PULSE                   1
#define PIN_NES_DATA                    5
#endif

#define SPLASH_DURATION_MS          3000u

//********************************************************************************
// TYPEDEFS AND STRUCTS
//********************************************************************************
typedef enum
{
    BUTTON_A = 0,
    BUTTON_B,
    BUTTON_SELECT,
    BUTTON_START,
    BUTTON_UP,
    BUTTON_DOWN,
    BUTTON_LEFT,
    BUTTON_RIGHT,
    BUTTON_HOME,
    BUTTON_COUNT
} controller_button_t;

typedef enum
{
    OSD_LINE_COLOR_SCHEME = 0,
    OSD_LINE_FRAME_BLENDING,
    OSD_LINE_AUDIO_GAIN,
    OSD_LINE_RESET_DEVICE,
    OSD_LINE_SAVE_SETTINGS,
    OSD_LINE_EXIT,
    OSD_LINE_COUNT
} osd_line_t;

typedef enum
{
    BUTTON_STATE_PRESSED = 0,
    BUTTON_STATE_UNPRESSED
} button_state_t;


typedef enum
{
    SAVE_INDEX_SCHEME = 0,
    SAVE_INDEX_FRAME_BLENDING
} save_position_t;

typedef enum
{
    DISABLE_MASK_NONE = 0,
    DISABLE_MASK_MASS_STORAGE,
    DISABLE_MASK_PICOBOOT
} interface_disable_mask_t;

typedef enum
{
    RESTART_NORMAL = 0,
    RESTART_MASS_STORAGE,
} restart_option_t;


//********************************************************************************
// PRIVATE VARIABLES
//********************************************************************************
// Packed DMA buffers - 4 pixels per byte (2 bits each)
// This is the native format from the Game Boy (2 bits per pixel)
// Used by BOTH 640x480 and 800x600 modes for DMA capture AND display
static uint8_t packed_buffer_0[PACKED_FRAME_SIZE] = {0};
static uint8_t packed_buffer_1[PACKED_FRAME_SIZE] = {0};
static uint8_t packed_buffer_previous[PACKED_FRAME_SIZE] = {0};  // For frame blending

// TMDS encoder handles palette conversion and horizontal scaling
static volatile uint8_t* packed_display_ptr = packed_buffer_0;
// static uint8_t* packed_render_ptr = packed_buffer_1;

// Frame blending - blends previous frame with current for sprite overlay effects
static volatile bool frame_blending_enabled = false;

// Frame blending lookup tables for ultra-fast processing
// Precomputed lookup table for brightening effect (256 bytes)
// Only store_lut is needed; blend calculation is done inline to save 64KB of RAM
static uint8_t store_lut[256];             // What to store for next frame

// PIO video capture
// PIO NOTES:
// - Each PIO instance has a 32 instruction limit
// - Pico allows for 4 state machines per PIO instance
// - the 32 instructions are shared among all state machines in that PIO instance
// PIO1:
// - Video capture PIO uses 31 instructions, so we can't have any more PIO programs on PIO1
// PIO0:
// - DVI uses SM0, SM1, SM2, but all 3 use the same program (instruction count = 2)
// - I think we can use SM3 for DMG buttons PIO

static PIO pio_video = pio1;  // Exclusively for video capture
static uint video_sm = 0;
static uint video_offset = 0;

static uint8_t button_states[BUTTON_COUNT];
static uint8_t button_states_previous[BUTTON_COUNT];

struct dvi_inst dvi0;

// RGB888 palettes - shared by both 640x480 and 800x600 modes
// Store in flash to save RAM
const uint32_t palette__dmg_nso[4] = {
    0x8cad28,  // GB 0 = White (DMG green lightest)
    0x6c9421,  // GB 1 = Light gray
    0x426b29,  // GB 2 = Dark gray
    0x214231   // GB 3 = Black (DMG green darkest)
};

const uint32_t palette__gbp_nso[4] = {
    0xb5c69c,  // GB 0 = White (GBP lightest)
    0x8d9c7b,  // GB 1 = Light gray
    0x6c7251,  // GB 2 = Dark gray
    0x303820   // GB 3 = Black (GBP darkest)
};

const uint32_t* game_palette_rgb888 = palette__gbp_nso;

uint8_t line_buffer[DMG_PIXELS_X / 4] = {0};  // 40 bytes for 160 pixels packed

#if ENABLE_AUDIO
// configuration
const struct analog_microphone_config mic_config = {
    // GPIO to use for input, must be ADC compatible (GPIO 26 - 28)
    .gpio = PIN_AUDIO_IN,

    // bias voltage of microphone in volts
    .bias_voltage = 1.65f,

    // sample rate in Hz - match HDMI audio
    .sample_rate = SAMPLE_FREQ,

    // ADC fills 128 samples every 4ms, timer reads 128 samples every 4ms
    // Cuts DMA IRQ frequency vs the original 64-sample cadence without long-latency buzz
    .sample_buffer_size = ADC_CHUNK_SIZE,
#if PICO_RP2350 && AUDIO_ON_CORE1
    .dma_irq = DMA_IRQ_3    // POC - not really needed
#else
    .dma_irq = -1  // Use default DMA IRQ
#endif
};
// variables - use double buffering to avoid race conditions
int16_t sample_buffer_a[ADC_CHUNK_SIZE];
int16_t sample_buffer_b[ADC_CHUNK_SIZE];
volatile int16_t* adc_write_buffer = sample_buffer_a;  // ADC writes here
volatile int16_t* adc_read_buffer = sample_buffer_b;   // timer reads from here

// Fixed buffer that audio always reads from (ADC copies to this)
int16_t sample_buffer_for_audio[ADC_CHUNK_SIZE];
#endif // ENABLE_AUDIO

static volatile bool dma_irq_ready_core1 = false;

static restart_option_t restart_option = RESTART_NORMAL;

// Duplicated from tmds_encode.c
static const __unused uint32_t __scratch_x("tmds_table") tmds_table[] = {
#include "tmds_table.h"
};

// Adafruit HSTX
static const struct dvi_serialiser_cfg adafruit_hstx_cfg = {
	.pio = DVI_DEFAULT_PIO_INST,
	.sm_tmds = {0, 1, 2},
	.pins_tmds = {18, 16, 12},
	.pins_clk = 14,
	.invert_diffpairs = false
};

//********************************************************************************
// PRIVATE FUNCTION PROTOTYPES
//********************************************************************************
static void core1_main(void);
static void __no_inline_not_in_flash_func(prepare_scanline_2bpp_gameboy)(struct dvi_inst *inst, const uint8_t *packed_scanbuf);
static void __not_in_flash_func(tmds_encode_2bpp_packed_gameboy)(const uint8_t *packed_pixbuf,
                                    uint32_t *symbuf_r,
                                    uint32_t *symbuf_g,
                                    uint32_t *symbuf_b,
                                    size_t output_words,
                                    uint32_t horizontal_repeat,
                                    size_t input_pixels,
                                    const uint32_t *palette_rgb888);
static void __no_inline_not_in_flash_func(core1_scanline_callback)(uint scanline);
static void init_frame_blending_luts(void);
static void set_game_palette(int index);
static void initialize_gpio(void);
static bool __no_inline_not_in_flash_func(game_controller)(void);
static bool button_is_pressed(controller_button_t button);
static bool button_was_released(controller_button_t button);
static bool command_check(void);
static void button_state_save_previous(void);
static void reset_button_states(void);
static void save_settings(void);
static void reset_pico(restart_option_t restart_option);
static void load_settings(void);

#if ENABLE_AUDIO
static void on_analog_samples_ready(void);
// static void __not_in_flash_func(on_analog_samples_ready)(void);
#endif // ENABLE_AUDIO

static void __no_inline_not_in_flash_func(gpio_callback)(uint gpio, uint32_t events);
static void update_osd(void);
static void change_audio_gain(float delta);

//********************************************************************************
// PRIVATE FUNCTIONS
//********************************************************************************
static void core1_main(void)
{
    // Initialize shared DMA handler on Core 1 so audio DMA IRQs stay off Core 0
    // use dma_irq from config
    SHARED_DMA_Init(mic_config.dma_irq);
    printf("Shared DMA IRQ handler installed on Core 1\n");

    dma_irq_ready_core1 = true;
    // Notify core0 that DMA IRQ handler is armed
    multicore_fifo_push_blocking(0xDACEB00C);  // arbitrary value, just a signal
    dvi_register_irqs_this_core(&dvi0, DMA_IRQ_0);
    dvi_start(&dvi0);
    
#if ENABLE_AUDIO && AUDIO_ON_CORE1
    absolute_time_t next_audio_tick = delayed_by_ms(get_absolute_time(), AUDIO_TICK_MS);
#endif

    while (true)
    {
        const uint8_t *scanbuf = NULL;
        if (queue_try_remove_u32(&dvi0.q_colour_valid, (uint32_t*)&scanbuf))
        {
            prepare_scanline_2bpp_gameboy(&dvi0, scanbuf);
            queue_add_blocking_u32(&dvi0.q_colour_free, (uint32_t*)&scanbuf);
        }

#if ENABLE_AUDIO && AUDIO_ON_CORE1
        // Run audio chunking on Core 1 to reduce contention with VSYNC GPIO handling on Core 0
        if (time_reached(next_audio_tick)) 
        {
            emu_audio_manual_tick();
            next_audio_tick = delayed_by_ms(next_audio_tick, AUDIO_TICK_MS);
        }
#endif
    }
}

static void __no_inline_not_in_flash_func(prepare_scanline_2bpp_gameboy)(struct dvi_inst *inst, const uint8_t *packed_scanbuf)
{
    static uint scanline_idx = 0;

    uint32_t *tmdsbuf = NULL;
    queue_remove_blocking_u32(&inst->q_tmds_free, &tmdsbuf);
    uint pixwidth = inst->timing->h_active_pixels;             // e.g., 800
    uint words_per_channel = pixwidth / DVI_SYMBOLS_PER_WORD;  // e.g., 400 when SPW=2

    static const uint32_t default_palette[4] = {
        0xb5c69c, 0x8d9c7b, 0x6c7251, 0x303820
    };
    const uint32_t *palette = (const uint32_t*)inst->blank_settings.palette_rgb888;
    if (palette == NULL) {
        palette = default_palette;
    }

    const uint current_scanline = scanline_idx;
    scanline_idx = (scanline_idx + 1) % SCANLINE_COUNT;

    const bool in_active_window =
        (current_scanline >= VERTICAL_OFFSET) &&
        (current_scanline < (DMG_PIXELS_Y + VERTICAL_OFFSET));

    if (!in_active_window || packed_scanbuf == NULL)
    {
        // Force full black using TMDS zero symbol (not palette-derived) for porches/blank lines
        const uint32_t black_word = tmds_table[0];
        for (uint word_idx = 0; word_idx < words_per_channel; ++word_idx) {
            tmdsbuf[2 * words_per_channel + word_idx] = black_word;
            tmdsbuf[1 * words_per_channel + word_idx] = black_word;
            tmdsbuf[0 * words_per_channel + word_idx] = black_word;
        }
    } 
    else 
    {
        tmds_encode_2bpp_packed_gameboy(
            packed_scanbuf,
            tmdsbuf + 2 * words_per_channel,  // Red
            tmdsbuf + 1 * words_per_channel,  // Green
            tmdsbuf + 0 * words_per_channel,  // Blue
            words_per_channel,
            HORIZONTAL_SCALE,
            DMG_PIXELS_X,
            palette);
    }

    queue_add_blocking_u32(&inst->q_tmds_valid, &tmdsbuf);
}
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
int main(void)
{
    vreg_set_voltage(VREG_VSEL);
    sleep_ms(10);
    set_sys_clock_khz(DVI_TIMING.bit_clk_khz, true);
    reset_button_states();

    // Initialize frame blending lookup tables (one-time computation)
    // Both modes use packed buffers for capture, so both need LUTs
    init_frame_blending_luts();
    
    // Mario image is now pre-packed in 2bpp format
    // Simply copy the packed data directly to the display buffers
    memcpy(packed_buffer_0, mario_packed_160x144, PACKED_FRAME_SIZE);
    memcpy(packed_buffer_1, packed_buffer_0, PACKED_FRAME_SIZE);

    // Both modes use packed buffer directly (TMDS encoder handles palette and scaling)
    packed_display_ptr = packed_buffer_0;
    // TODO packed_render_ptr = packed_buffer_1;

    // Initialize OSD overlays (disabled by default)
    OSD_init(DMG_PIXELS_X, DMG_PIXELS_Y);
    OSD_clear();
    OSD_set_enabled(false);

    dvi0.timing = &DVI_TIMING;
    dvi0.ser_cfg = DVI_SERIAL_CONFIG;
    //dvi0.scanline_callback = (dvi_callback_t*)core1_scanline_callback;
    dvi0.scanline_callback = core1_scanline_callback;
    dvi_init(&dvi0, next_striped_spin_lock_num(), next_striped_spin_lock_num());

    load_settings();

    uint32_t *bufptr = (uint32_t*)line_buffer;
    queue_add_blocking_u32(&dvi0.q_colour_valid, &bufptr);
    queue_add_blocking_u32(&dvi0.q_colour_valid, &bufptr);

    // HDMI Audio related
    // Support 16000, 22050, 24000, 32000, 44100, and 48000 Hz sample rates
#if ENABLE_AUDIO
    int offset;
    if (rate == 48000) {
        offset = 2;
    } else if (rate == 44100) {
        offset = 1;
    } else if (rate == 24000) {
        offset = 5;  // 24kHz - well supported
    } else if (rate == 22050) {
        offset = 3;  // Half of 44.1k
    } else if (rate == 16000) {
        offset = 4;  // Half of 32k
    } else {
        offset = 0;  // Default for other rates (32000)
    }
    int cts = dvi0.timing->bit_clk_khz*hdmi_n[offset]/(rate/100)/128;
    dvi_get_blank_settings(&dvi0)->top    = 0;
    dvi_get_blank_settings(&dvi0)->bottom = 0;
    dvi_audio_sample_buffer_set(&dvi0, audio_buffer, AUDIO_BUFFER_SIZE);
    dvi_set_audio_freq(&dvi0, rate, cts, hdmi_n[offset]);
    // Note: dvi_set_audio_freq() automatically calls dvi_enable_data_island()
    
    // Pre-fill buffer to 25% to allow for bursty DVI consumption patterns
    increase_write_pointer(&dvi0.audio_ring, AUDIO_BUFFER_SIZE / 4);
    printf("Audio buffer pre-filled to %d samples (25%%)\n", AUDIO_BUFFER_SIZE / 4);
#endif

    // OPTIMIZED ORDER for audio + video:
    // 1. Start audio timer (500Hz chunk processing)
    // 2. Start Core1 (DVI output starts consuming audio)
    // 3. Initialize ADC microphone
    // 4. Initialize GPIO/PIO for DMG controller
    // 5. Register VSYNC interrupt (video capture begins)

#if ENABLE_AUDIO
    if (AUDIO_ON_CORE1) {
        emu_audio_set_manual_tick(true);
        printf("Audio: manual tick on Core1 every %d ms\n", AUDIO_TICK_MS);
    } else {
        emu_audio_set_manual_tick(false);
        printf("Starting audio timer (500Hz chunk rate)...\n");
    }
	emu_sndInit(false, false, &dvi0.audio_ring, sample_buffer_for_audio);
    emu_audio_set_gain(AUDIO_GAIN);
    emu_audio_set_highpass(AUDIO_HPF_HZ);
    emu_audio_set_lowpass(AUDIO_LPF_HZ);
    printf("Audio system initialized\n");
    
#endif

#if ENABLE_VIDEO_CAPTURE

    printf("Initializing PIO video capture...\n");
    video_offset = pio_add_program(pio_video, &video_capture_irq_program);
    video_capture_program_init(pio_video, video_sm, video_offset);

    // Video uses polled completion; pass -1 to avoid enabling any DMA IRQ
    int video_dma_chan = video_capture_dma_init(pio_video, video_sm, -1, packed_buffer_0, PACKED_FRAME_SIZE);
    if (video_dma_chan < 0)
    {
        printf("ERROR: Video capture DMA initialization failed!\n");
        while (1) { tight_loop_contents(); }
    }
    // Video uses polled completion (no IRQ) to avoid contention
    printf("  -> DMA initialized (packed format: %d bytes, polled completion)\n", PACKED_FRAME_SIZE);
    // stdio_flush();
#endif

    // Always start DVI output on Core 1, regardless of audio
    printf("Starting Core 1 (DVI output)...\n");
    multicore_launch_core1(core1_main);
    printf("Core 1 running - now consuming video!\n");

    // Wait for Core1 to arm DMA IRQ handler before starting analog mic DMA
    if (AUDIO_ON_CORE1) {
        while (!dma_irq_ready_core1) {
            // Also drain FIFO token if core1 already signaled
            if (multicore_fifo_rvalid()) {
                multicore_fifo_pop_blocking();
            }
            tight_loop_contents();
        }
        // Drain any pending FIFO token
        if (multicore_fifo_rvalid()) multicore_fifo_pop_blocking();
    }

#if ENABLE_AUDIO
    printf("Initializing analog microphone on GPIO %d at %d Hz...\n", mic_config.gpio, mic_config.sample_rate);
    if (analog_microphone_init(&mic_config) < 0) {
        printf("ERROR: analog microphone initialization failed!\n");
        while (1) { tight_loop_contents(); }
    }
    printf("Analog microphone initialized successfully\n");

    analog_microphone_set_samples_ready_handler(on_analog_samples_ready);
    printf("ADC callback handler registered\n");

    printf("Starting analog microphone DMA capture...\n");
    if (analog_microphone_start() < 0) {
        printf("ERROR: PDM microphone start failed!\n");
        while (1) { tight_loop_contents(); }
    }
    printf("Analog microphone started successfully - DMA should be running\n");
#endif

    initialize_gpio();

    for (int i = 0; i < 5; i++) {
        printf("\n\n=== PicoDVI-DMG_EMU Starting (attempt %d) ===\n", i + 1);
        sleep_ms(100);
    }

    printf("Firmware build: %s %s\n", __DATE__, __TIME__);

    // Set up shared GPIO callback - this handles BOTH DMG buttons AND VSYNC
    gpio_set_irq_enabled_with_callback(DMG_READING_DPAD_PIN, GPIO_IRQ_EDGE_FALL | GPIO_IRQ_EDGE_RISE, true, &gpio_callback);
    gpio_set_irq_enabled(DMG_READING_BUTTONS_PIN, GPIO_IRQ_EDGE_FALL | GPIO_IRQ_EDGE_RISE, true);  // Callback already registered

    // Enable VSYNC interrupt (GPIO 7) after callback registration
#if ENABLE_VIDEO_CAPTURE
    irq_set_priority(IO_IRQ_BANK0, 0x00);  // Max priority to avoid missing VSYNC edges
    gpio_set_irq_enabled(VSYNC_PIN, GPIO_IRQ_EDGE_RISE, true);
    printf("VSYNC GPIO interrupt enabled (rising edge)\n");
#endif

    // Track which packed buffer is being captured (both modes use packed buffers)
    uint8_t* packed_capture = packed_buffer_0;
    // uint8_t* packed_next = packed_buffer_1;
    bool video_capture_active = false;
    bool video_capture_started = false;

    // Hold off controller polling briefly after boot to avoid early contention with VSYNC/audio
    const absolute_time_t controller_poll_enable_time = delayed_by_ms(get_absolute_time(), 1000);
    
    absolute_time_t splash_until = delayed_by_ms(get_absolute_time(), SPLASH_DURATION_MS);
    bool splash_done = false;

    update_osd();

    // Main loop - PIO video + good audio
    while (true) 
    {
        static uint32_t loop_counter = 0;
        static uint32_t frames_captured = 0;
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

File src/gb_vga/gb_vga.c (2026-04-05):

/* 
    Authors: 
        Andy West (original concept and code)
        Joe Ostrander
            - conversion to single Pico (gpio callbacks, bit-depth reduction, etc.)
            - on-screen display for custom settings
            - I2C game controller code
            - save settings to flash
            - video mode conversion 4:3 + border
            - frame blending

        You too can contribute and I welcome any suggestions!


    https://github.com/joeostrander/consolized-game-boy

    Note about scanvideo:
    When scaling, there is a bug in scanvideo.c that prevents line zero from repeating
    see my fix --> https://github.com/joeostrander/pico-extras/commit/3ed9467f0203acd9bedfdbb08bed8f31b61b320c
*/

#include <stdio.h>
#include <stdlib.h>
#include <string.h> // for memcmp
#include "time.h"
#include "pico.h"
#include "pico/stdlib.h"
#include "pico/multicore.h"
#include "pico/scanvideo.h"
#include "pico/scanvideo/composable_scanline.h"
#include "pico/sync.h"
#include "hardware/vreg.h"
#include "pico/stdio.h"
#include "osd.h"
#include "hardware/i2c.h"
#include "colors.h"
#include "eeprom.h"
#include "hardware/dma.h"
#include "hardware/flash.h"
#include "hardware/irq.h"
#include "hardware/clocks.h"
#include "hardware/watchdog.h"
#include "pico/bootrom.h"
#include "video_capture.pio.h"  // PIO-based video capture

// #define TEST_MARIO_FRAMEBUFFER

#ifdef TEST_MARIO_FRAMEBUFFER
#include "mario.h"
#endif

#ifndef USE_RGB332_PCB
#define USE_RGB332_PCB                  0     // set to 0 to use RGB222
#endif

#ifndef USE_NES_CLASSIC_OR_WII
#define USE_NES_CLASSIC_OR_WII  0 // Set to 1 to use I2C controller (NES Classic or Wii)
#endif

#if USE_NES_CLASSIC_OR_WII
// I2C Pins, etc. -- for I2C controller
#define SDA_PIN     12
#define SCL_PIN     13
#define I2C_ADDRESS 0x52
i2c_inst_t* i2cHandle = i2c0;
#else // use old-school NES controller
// Shift register pins -- for old-school NES controller
#define DATA_PIN                8
#define LATCH_PIN               9
#define PULSE_PIN               10
#endif

#define MIN_RUN 3

#define ONBOARD_LED_PIN             25

// GAMEBOY VIDEO INPUT (From level shifter)
#define VSYNC_PIN                   18
#define HSYNC_PIN                   17
#define PIXEL_CLOCK_PIN             16
#define DATA_1_PIN                  15
#define DATA_0_PIN                  14

#define DMG_READING_DPAD_PIN        19      // P14
#define DMG_READING_BUTTONS_PIN     20      // P15
#define DMG_OUTPUT_LEFT_B_PIN       26      // P11
#define DMG_OUTPUT_DOWN_START_PIN   21      // P13
#define DMG_OUTPUT_UP_SELECT_PIN    22      // P12
#define DMG_OUTPUT_RIGHT_A_PIN      27      // P10

#define GAMEBOY_RESET_PIN           28

// at 3x Game area will be 480x432 
#define DMG_PIXELS_X                160
#define DMG_PIXELS_Y                144
#define DMG_PIXEL_COUNT             (DMG_PIXELS_X*DMG_PIXELS_Y)
#define PACKED_FRAME_SIZE           (DMG_PIXEL_COUNT / 4)

//**********************************************************************************************
// TYPEDEFS & STRUCTS
//**********************************************************************************************
typedef enum
{
    SAVE_INDEX_SCHEME = 0,
    SAVE_INDEX_BORDER,
    SAVE_INDEX_FRAME_BLENDING
} save_position_t;

typedef enum
{
    BUTTON_A = 0,
    BUTTON_B,
    BUTTON_SELECT,
    BUTTON_START,
    BUTTON_UP,
    BUTTON_DOWN,
    BUTTON_LEFT,
    BUTTON_RIGHT,
    BUTTON_HOME,
    BUTTON_COUNT
} controller_button_t;

typedef enum
{
    OSD_LINE_COLOR_SCHEME = 0,
    OSD_LINE_BORDER_COLOR,
    OSD_LINE_FRAMEBLENDING,
    OSD_LINE_RESET_GAMEBOY,
    OSD_LINE_RESET_DEVICE,
    OSD_LINE_SAVE_SETTINGS,
    OSD_LINE_EXIT,
    OSD_LINE_COUNT
} osd_line_t;

typedef enum
{
    BUTTON_STATE_PRESSED = 0,
    BUTTON_STATE_UNPRESSED
} button_state_t;

typedef struct rectangle_t
{
    uint16_t x;
    uint16_t y;
    uint16_t width;
    uint16_t height;
} rectangle_t;

typedef enum
{
    DISABLE_MASK_NONE = 0,
    DISABLE_MASK_MASS_STORAGE,
    DISABLE_MASK_PICOBOOT
} interface_disable_mask_t;

typedef enum
{
    RESTART_NORMAL = 0,
    RESTART_MASS_STORAGE,
} restart_option_t;

//**********************************************************************************************
// PRIVATE VARIABLES
//**********************************************************************************************

const scanvideo_timing_t vga_timing_640x480_gb =
        {
                .clock_freq = 25000000,

                .h_active = 640,
                .v_active = 480,

                .h_front_porch = 16,
                .h_pulse = 64,
                .h_total = 800,
                .h_sync_polarity = 1,

                .v_front_porch = 1,
                .v_pulse = 2,
                .v_total = 523,
                .v_sync_polarity = 1,

                .enable_clock = 0,
                .clock_polarity = 0,

                .enable_den = 0
        };

const scanvideo_mode_t vga_mode_640x480_3x_scale =
{
        .default_timing = &vga_timing_640x480_gb,
        .pio_program = &video_24mhz_composable,
        .width = 640,
        .height = 480,
        .xscale = 3,
        .yscale = 3,
};

#define VGA_MODE vga_mode_640x480_3x_scale
#define LINE_LENGTH     ((uint16_t)(((VGA_MODE.width * 100.0)/VGA_MODE.xscale) + 50) / 100)

#define VGA_PIXEL_CLOCK_KHZ        (VGA_MODE.default_timing->clock_freq / 1000u)
#define VGA_SYS_CLOCK_MULTIPLIER   10u
#define VGA_SYS_CLOCK_KHZ          (VGA_PIXEL_CLOCK_KHZ * VGA_SYS_CLOCK_MULTIPLIER)

static semaphore_t video_initted;
static uint8_t button_states[BUTTON_COUNT];
static uint8_t button_states_previous[BUTTON_COUNT];
static color_scheme_t* color_scheme;

static uint8_t* osd_framebuffer = NULL;
static uint8_t framebuffer_active[DMG_PIXEL_COUNT] = {0};
static uint8_t framebuffer_previous[DMG_PIXEL_COUNT] = {0};
static uint8_t packed_buffer_0[PACKED_FRAME_SIZE] = {0};
static uint8_t packed_buffer_1[PACKED_FRAME_SIZE] = {0};
static bool frameblending_enabled = false;

static rectangle_t rect_gamewindow;
static rectangle_t rect_osd;
static uint16_t background_color;

static restart_option_t restart_option = RESTART_NORMAL;

static PIO pio_video = pio1;  // Exclusively for video capture
static uint video_sm = 0;
static uint video_offset = 0;
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

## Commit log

2023-01-15 V3.2 Add Link Port
    Add Link Port to SGB Version
    [BOM_GAMEBOY_CONSOLIZER_SGB_v3_2_2023-01-14.csv]
2023-01-15 - removing support for Original NES controller - OSD now toggled via HOME button on Wii/NES Classic controller - removing PDF schematics - adding EasyEDA project files - renaming to version #s to MOD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
    [nes_hdmi_mount.stl, wii_and_hdmi.stl, wii_jack_holder_top.stl]
2023-01-16 3.21 Board, DMG Link Mount
    3.21 Board Changes, a little cleanup, notch for back center screw post.
    Wii Board changed and labeled 3V3 not VCC.
    DMG Link Port Model and Breakout Board.
    [BOM_GAMEBOY_CONSOLIZER_SGB_v3_2_2023-01-14.csv, BOM_V3_2_SGB_CART_2023-01-14.csv, dmg_link_mount.stl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]
2023-01-17 Matched up to Joe's
    Matched up to Joe's restructure
    [dmg_link_mount.stl, wii_hdmi_mount.stl]
2023-01-17 Restructure to match Joe's
    [BOM_V3_2_SGB_CART_2023-01-14.csv]
2023-01-18 minor breakout board revisions added easyeda files
    [BOM_V3_21_SGB_CART_2023-01-14.csv]
2023-01-19 fixed ROUT/LOUT version change to 3.2.2
    [BOM_V3_2_2_SGB_CART_2023-01-14.csv]
2023-01-25 bugfix - color scheme selection issue
    [gb_vga.c]
2023-05-07 - Removed pixel & scanline effects -- they were cheesy - Changed code to use scanvideo built-in video mode scaling, eliminating the need to manually scale - Changed Gameboy video scanning to use gpio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
2023-10-05 - Turns out I had bit order reversed on VGA. One option would have been to swap resistors for bit 6/7 of each color channel... instead I decided to swap bits in code. - disabling the onboard LED blin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
    [gb_vga.c]
2023-10-13 re-adding old-school nes controller support reordering the color schemes adding OSD line option to reverse RGB bits
    [gb_vga.c, osd.h]
2023-10-20 possible bugfix for controller issue that appears in some games
    [gb_vga.c]
2023-10-21 bugfix - was reading i2c controllers too fast - fine for myarcade wireless, but not for nes classic controller
    [gb_vga.c]
2023-10-25 frameblending test uf2
2023-10-28 v2.4.0 - added frameblending - fixed some video issues - fixed some issues what appeared when using wired NES Classic controller
    [gb_vga.c]
2024-06-28 save framebuffer setting to flash reset to usb drive
    [gb_vga.c, osd.h]
2024-07-01 workaround for the settings save lockup
    [gb_vga.c]
2026-04-05 restructure merge in gb_dvi
    [HDMI_BOM_SGB_CART.csv, HDMI_hstx_mount.stl, HDMI_wii_jack_holder_bottom_retainer_v2.stl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]
